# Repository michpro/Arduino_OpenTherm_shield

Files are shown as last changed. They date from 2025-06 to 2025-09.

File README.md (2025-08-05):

# **Arduino UNO OpenTherm Shield**

- [**Arduino UNO OpenTherm Shield**](#arduino-uno-opentherm-shield)
  - [**Overview**](#overview)
    - [**Features**](#features)
  - [**Schematic diagram**](#schematic-diagram)
  - [**Module visualisation**](#module-visualisation)
  - [**Assembly**](#assembly)
  - [**Production files**](#production-files)
  - [**Testing out the hardware**](#testing-out-the-hardware)
    - [Prerequisites](#prerequisites)
    - [Instructions](#instructions)
    - [Notes](#notes)
  - [**Software**](#software)
  - [**Reporting bugs**](#reporting-bugs)
  - [**License**](#license)
    - [**Hardware**](#hardware)
    - [**Software**](#software-1)
  - [**Support**](#support)

---

## **Overview**
The Arduino OpenTherm Shield is an open-source hardware interface designed to enable an Arduino microcontroller to communicate with heating systems using the OpenTherm protocol.
OpenTherm is a point-to-point communication protocol commonly used in modern heating systems for efficient control and monitoring.
This shield provides the necessary voltage conversion, electrical isolation, and signal conditioning to interface the Arduinos 5V or 3.3V logic
with the OpenTherm bus, which typically operates at higher voltages (24V).

  ### **Features**
  * OpenTherm slave interface to communicate with a boiler
  * OpenTherm master interface to communicate with a thermostat
  * can implement master, slave and gateway modes
  * built-in (3.3-5V) to 24V DC-DC step up converter
  * Arduino UNO compatible shield

This work is based on [otgw.tclcode.com](https://otgw.tclcode.com) project.

---

## **Schematic diagram**
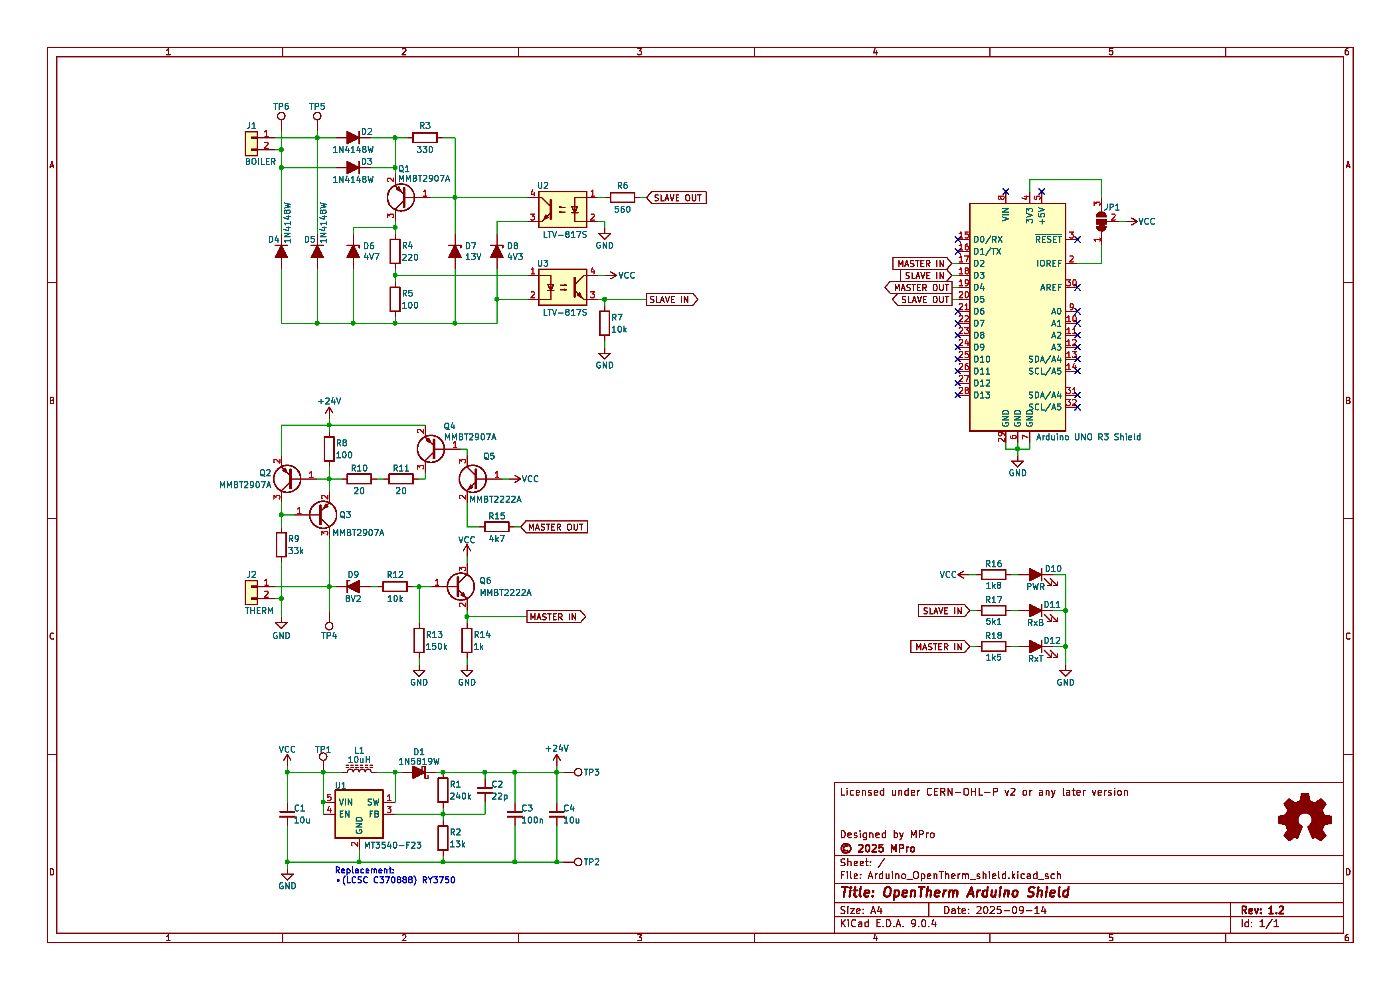
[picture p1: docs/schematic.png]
wiring diagram


## **Module visualisation**
(click on the image to see the 3D model)
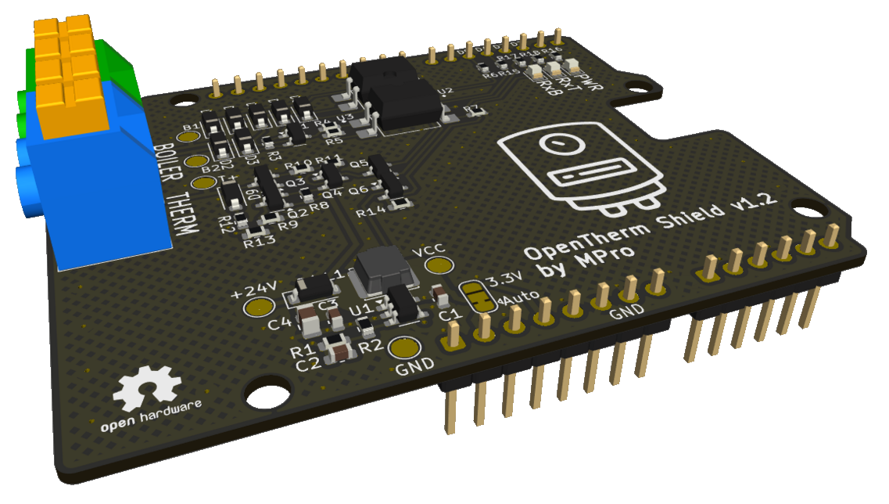
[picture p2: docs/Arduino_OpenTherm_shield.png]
Arduino UNO OpenTherm Shield
<p align="center"></p>

## **Assembly**
[Interactive BOM and placement](https://michpro.github.io/Arduino_OpenTherm_shield/ibom.html)

For Arduino UNO:
* JP1 jumper – leave in the Auto position (V<sub>cc</sub> from IOREF).

For WeMos D1 UNO:
* JP1 jumper - this board is not fully compatible with Arduino specifications - the IOREF pin on this board should have a voltage of 3.3V, but it has 5V. Therefore, cut the default jumper between the Auto and V<sub>cc</sub> pads and use a drop of tin to connect the V<sub>cc</sub> pad to 3.3V.<br>*You can also modify the WeMos D1 UNO so that the IOREF pin has the correct voltage of 3.3V*.

Other boards:
* This shield should also be compatible with other boards. You only need to check the correct voltage on the IOREF pin (and possibly make a change as for WeMos D1 UNO) and, if necessary, adjust the software to the board definition.

## **Production files**
Production files can be found [**here**](./production/).

---

## **Testing out the hardware**
Below are the start-up instructions for the ["shield_test.ino"](./software/shield_test/shield_test.ino) Arduino program, a diagnostic tool designed to test and validate the electrical and communication integrity between a boiler and thermostat circuits on the OpenTherm shield. These instructions guide you through the process step-by-step, ensuring you can verify your hardware setup correctly.

### Prerequisites
- **Arduino Board**: Use an AVR family board (e.g., Arduino UNO).
- **OpenTherm Shield**: Ensure it is properly connected to the Arduino.
- **Computer**: Equipped with Arduino IDE or a serial monitor software.
- **Multimeter**: Required for measuring voltages and currents.
- **Two Wires**: Needed to connect the BOILER and THERM terminals during testing.

### Instructions

1. **Upload the Program**
   - Load the ["shield_test.ino"](./software/shield_test/shield_test.ino) program onto your Arduino board (Arduino UNO preffered) using the Arduino IDE.<br>
    *If necessary, adjust the pins used in the programme.*

2. **Open Serial Monitor**
   - Launch the serial monitor in the Arduino IDE or your preferred serial terminal software.
   - Set the baud rate to **115200**.

3. **Initial Setup**
   - Disconnect the 'THERM' and 'BOILER' terminals from each other if they are connected.
   - Check the LEDs on the shield:
     - **'PWR'** and **'RxT'** LEDs should be lit.
     - **'RxB'** LED should be off.
   - The serial monitor will display a prompt. If the LED statuses match, type **`y`** and press Enter to proceed.

4. **Voltage Measurement 1**
   - Use a multimeter to measure the voltage between the **+24V test point** and **GND**.
   - Expected range: **23.5V to 24.5V**.
   - If within range, type **`y`** in the serial monitor to proceed.

5. **Voltage Measurement 2**
   - Measure the voltage between the **T+ test point** and **GND**.
   - Expected value: Approximately **24V**.
   - If correct, type **`y`** to proceed.

6. **Current Measurement 1**
   - Measure the current flowing between **T+** and **GND**.
   - Expected range: **5mA to 9mA**.
   - Verify that the **RxT LED** is **not lit** during this measurement.
   - If correct, type **`y`** to proceed.

7. **Activate MASTER-OUT and Current Measurement 2**
   - The program will activate the 'MASTER-OUT' line (you’ll see a message in the serial monitor).
   - Measure the current between **T+** and **GND** again.
   - Expected range: **17mA to 23mA**.
   - Ensure the **RxT LED** remains **not lit**.
   - If correct, type **`y`** to proceed.

8. **Connect Terminals and Voltage Measurement 3**
   - Connect the **BOILER** and **THERM** terminals using two wires (polarity does not matter).
   - Measure the voltage between test points **B1** and **B2**.
   - Expected range: **15V to 18V**.
   - If within range, type **`y`** to proceed.

9. **Check RxB LED**
   - The program will activate 'MASTER-OUT' again.
   - Observe the **'RxB' LED**; it should **light up**.
   - If it does, type **`y`** to proceed.

10. **Activate SLAVE-OUT and Voltage Measurement 4**
    - The program will activate the 'SLAVE-OUT' line.
    - Check that the **RxT LED** **stops lighting up**.
    - Measure the voltage between **B1** and **B2** again.
    - Expected range: **5V to 7V**.
    - If correct, type **`y`** to proceed.

11. **Test Result**
    - If all steps are completed successfully, the serial monitor will display:
      ```
      *****************
      *  TEST PASSED  *
      *****************
      ```
    - If any step fails, it will show:
      ```
      *****************
      * TEST FAIL !!! *
      *****************
      ```

12. **Continuous Testing (if passed)**
    - If the test passes, the program will enter a continuous testing mode.
    - It will repeatedly check communication between the boiler and thermostat, printing:
      - **"Boiler inbound, thermostat outbound ... OK"** or **"Failed"** with a reason.
      - **"Boiler outbound, thermostat inbound ... OK"** or **"Failed"** with a reason.

### Notes
- **Test Points and LEDs**: Ensure you correctly identify the test points (+24V, T+, GND, B1, B2) and LEDs (PWR, RxT, RxB) on the OpenTherm shield.
- **Safety**: Exercise caution when measuring voltages and currents to avoid short circuits.
- **Troubleshooting**: If a measurement falls outside the expected range:
  - Double-check your connections and multimeter settings.
  - Retry the step. Persistent issues may indicate a problem with the shield or setup.

<br>

***Follow these instructions carefully to test and validate your OpenTherm shield setup. Each step requires confirmation via the serial monitor, so keep it open and active throughout the process. Successful completion ensures your boiler and thermostat circuits are functioning correctly.***

---

## **Software**
- Recommended library for use in your OpenTherm projects: 
  [https://github.com/ihormelnyk/opentherm_library](https://github.com/ihormelnyk/opentherm_library)

---

## **Reporting bugs**

[Create an issue on GitHub](https://github.com/michpro/Arduino_OpenTherm_shield/issues)

---

## **License**
Copyright © 2025 Michal Protasowicki

### **Hardware**
  * Hardware part of this project is released under CERN Open Hardware Licence Version 2 - Permissive.

    

### **Software**
  * Software part of this project is released under MIT Licence.

    

---

## **Support**
If You find my projects interesting and You wanted to support my work, You can give me a cup of coffee or a keg of beer :)

&nbsp;&nbsp;&nbsp;&nbsp;&nbsp;&nbsp;&nbsp;&nbsp;&nbsp;&nbsp;

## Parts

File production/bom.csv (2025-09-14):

Designator | Footprint | Quantity | Value | LCSC Part #
C1 | 0603 | 1 | 10u | C19702
C2 | 0603 | 1 | 22p | C1653
C3 | 0603 | 1 | 100n | C14663
C4 | 0805 | 1 | 10u | C440198
D1 | D_SOD-123 | 1 | 1N5819W | C8598
D10 | 0805 | 1 | PWR | C84256
D11 | 0805 | 1 | RxB | C2297
D12 | 0805 | 1 | RxT | C2296
D2, D3, D4, D5 | D_SOD-123 | 4 | 1N4148W | C7420318
D6 | D_SOD-123 | 1 | 4V7 | C19077400
D7 | D_SOD-123 | 1 | 13V | C22399883
D8 | D_SOD-123 | 1 | 4V3 | C19077399
D9 | D_SOD-123 | 1 | 8V2 | C22399882
L1 | Inductor_4.2x4.4mm | 1 | 10uH | C177242
Q1, Q2, Q3, Q4 | SOT-23 | 4 | MMBT2907A | C7420352
Q5, Q6 | SOT-23 | 2 | MMBT2222A | C8512
R1 | 0603 | 1 | 240k | C4197
R10, R11 | 0603 | 2 | 20 | C22950
R12, R7 | 0603 | 2 | 10k | C25804
R13 | 0603 | 1 | 150k | C22807
R14 | 0603 | 1 | 1k | C21190
R15 | 0603 | 1 | 4k7 | C23162
R16 | 0603 | 1 | 1k8 | C4177
R17 | 0603 | 1 | 5k1 | C23186
R18 | 0603 | 1 | 1k5 | C22843
R2 | 0603 | 1 | 13k | C22797
R3 | 0603 | 1 | 330 | C23138
R4 | 0603 | 1 | 220 | C22962
R5, R8 | 0603 | 2 | 100 | C22775
R6 | 0603 | 1 | 560 | C23204
R9 | 0603 | 1 | 33k | C4216
U1 | SOT-23-5 | 1 | MT3540-F23 | C181783
U2, U3 | SMDIP-4_W9.53mm | 2 | LTV-817S | C109227

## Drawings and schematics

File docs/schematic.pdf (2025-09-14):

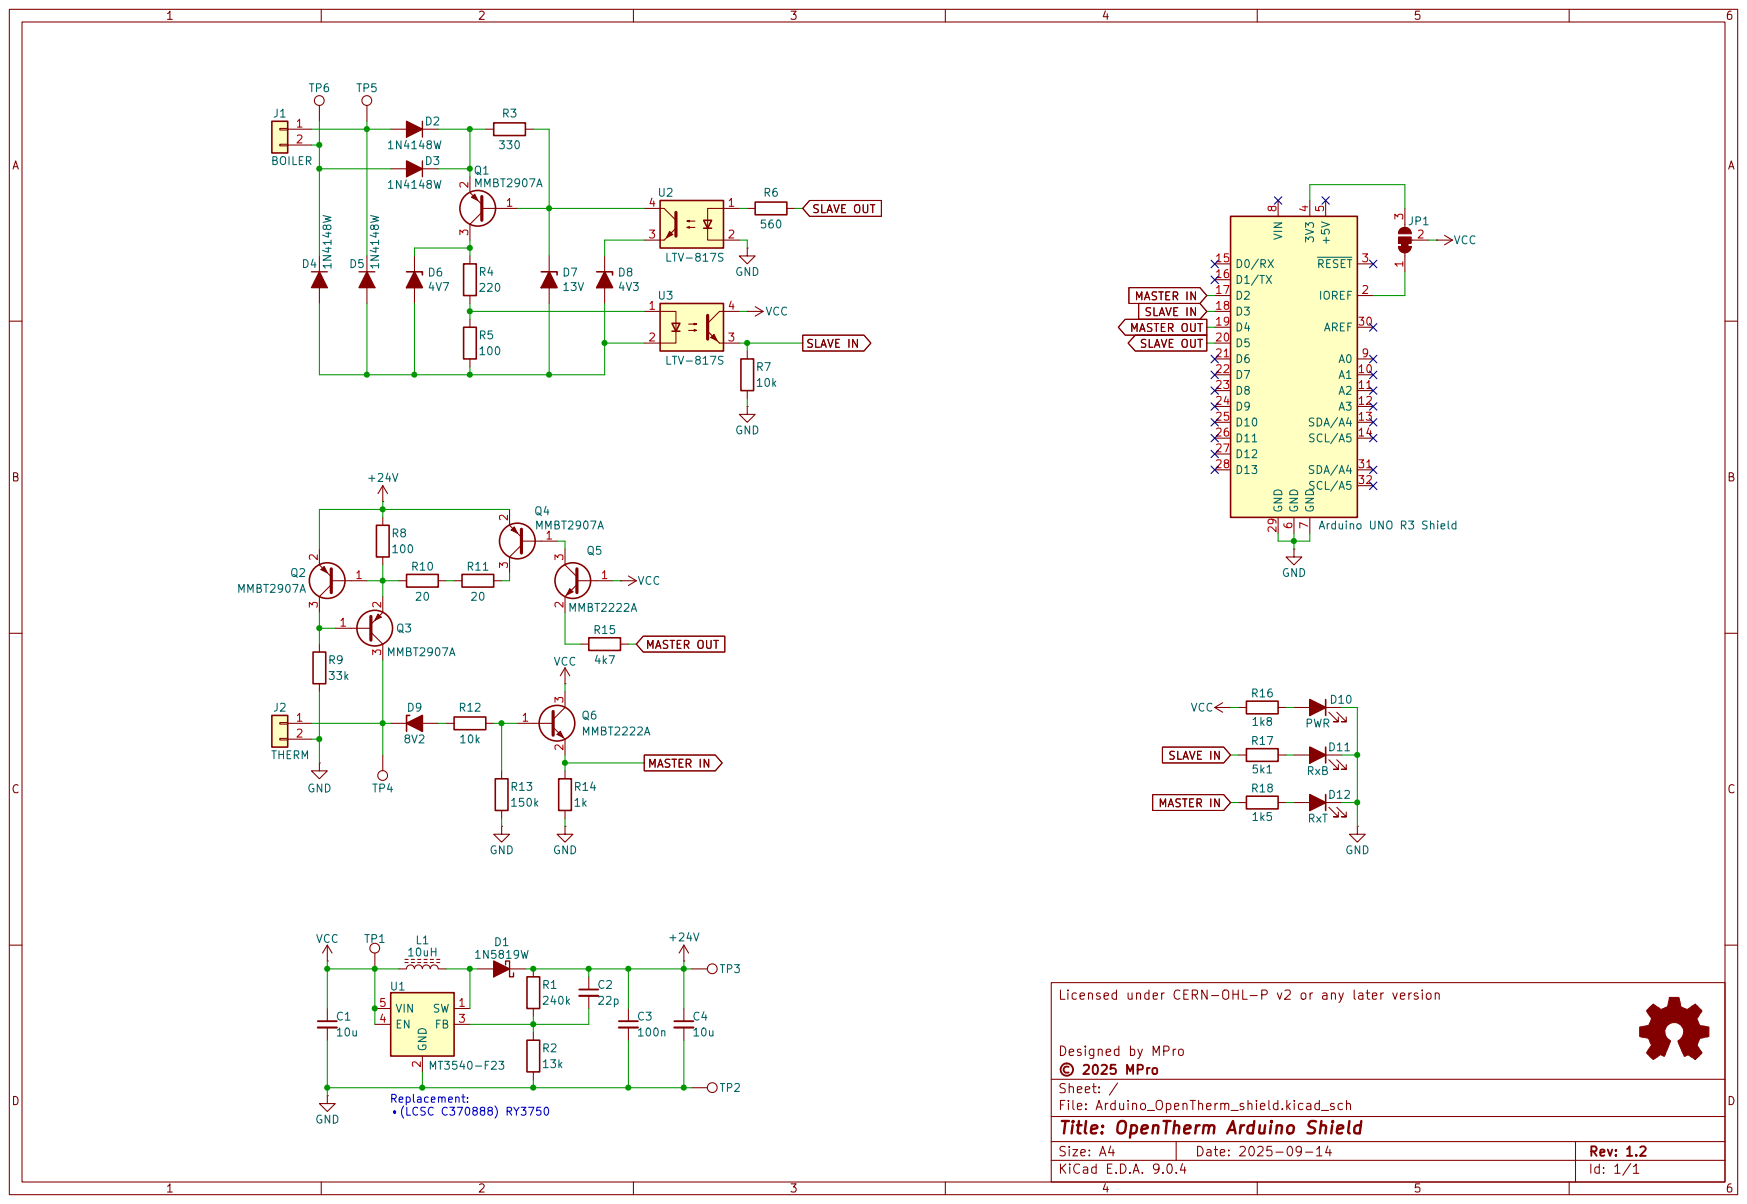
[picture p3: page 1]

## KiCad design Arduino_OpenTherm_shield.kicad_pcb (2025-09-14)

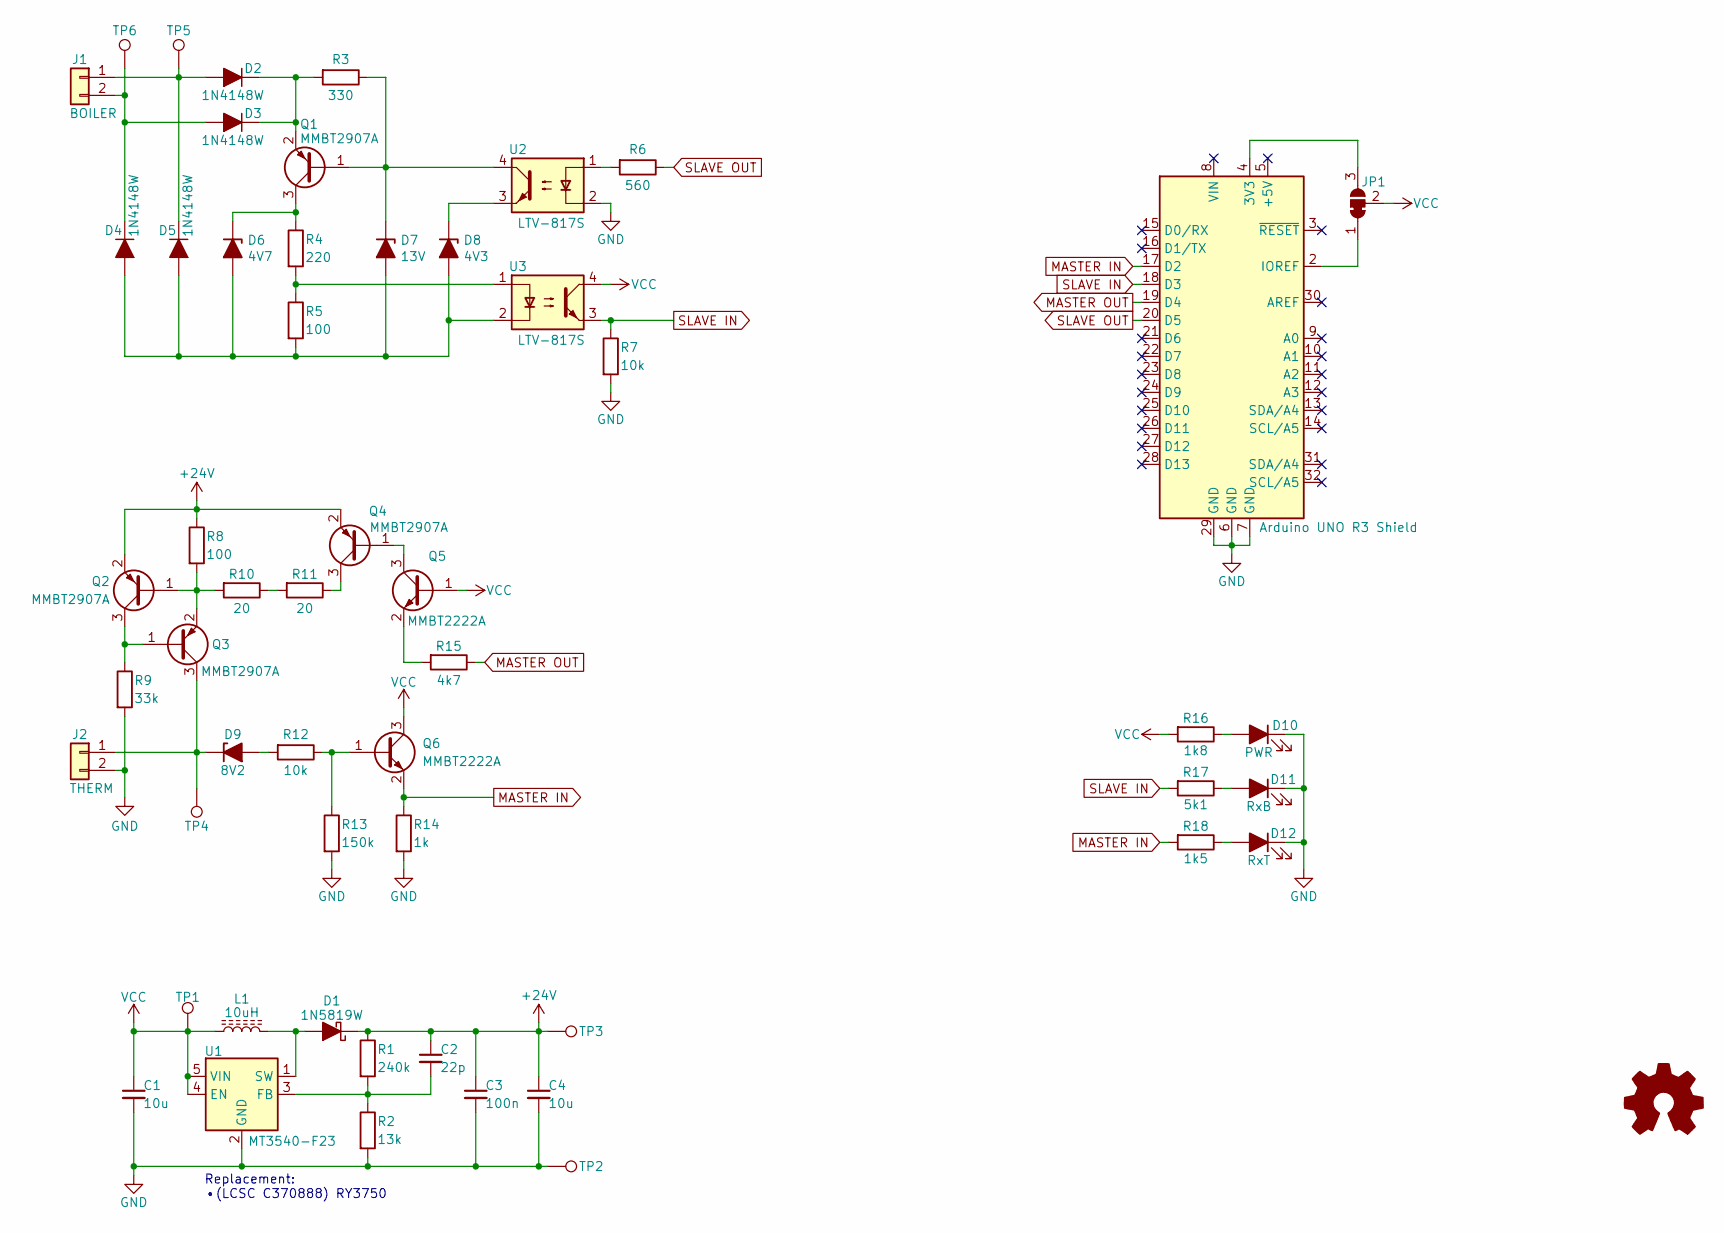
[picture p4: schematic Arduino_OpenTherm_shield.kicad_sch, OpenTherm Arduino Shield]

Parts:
A1: Arduino UNO R3 Shield; Arduino_UNO_R3_WithMountingHoles_Profiled; LCSC ------
C1: 10u; C_0603_1608Metric; LCSC C19702
C2: 22p; C_0603_1608Metric; LCSC C1653
C3: 100n; C_0603_1608Metric; LCSC C14663
C4: 10u; C_0805_2012Metric; LCSC C440198
D1: 1N5819W; D_SOD-123; LCSC C8598
D2, D3, D4, D5: 1N4148W; D_SOD-123; LCSC C7420318
D6: 4V7; D_SOD-123; LCSC C19077400
D7: 13V; D_SOD-123; LCSC C22399883
D8: 4V3; D_SOD-123; LCSC C19077399
D9: 8V2; D_SOD-123; LCSC C22399882
D10: PWR; LED_0805_2012Metric; LCSC C84256
D11: RxB; LED_0805_2012Metric; LCSC C2297
D12: RxT; LED_0805_2012Metric; LCSC C2296
J1: BOILER; Altech_AK100_1x02_P5.00mm; LCSC ------
J2: THERM; Altech_AK100_1x02_P5.00mm; LCSC ------
JP1: VCC; SolderJumper-3_P1.3mm_Bridged12_RoundedPad1.0x1.5mm; LCSC ------
L1: 10uH; Inductor_4.2x4.4mm; LCSC C177242
LOGO3: Logo_Open_Hardware_Small; OSHW-Logo2_7.3x6mm_SilkScreen
Q1, Q2, Q3, Q4: MMBT2907A; SOT-23; LCSC C7420352
Q5, Q6: MMBT2222A; SOT-23; LCSC C8512
R1: 240k; R_0603_1608Metric; LCSC C4197
R2: 13k; R_0603_1608Metric; LCSC C22797
R3: 330; R_0603_1608Metric; LCSC C23138
R4: 220; R_0603_1608Metric; LCSC C22962
R5, R8: 100; R_0603_1608Metric; LCSC C22775
R6: 560; R_0603_1608Metric; LCSC C23204
R7, R12: 10k; R_0603_1608Metric; LCSC C25804
R9: 33k; R_0603_1608Metric; LCSC C4216
R10, R11: 20; R_0603_1608Metric; LCSC C22950
R13: 150k; R_0603_1608Metric; LCSC C22807
R14: 1k; R_0603_1608Metric; LCSC C21190
R15: 4k7; R_0603_1608Metric; LCSC C23162
R16: 1k8; R_0603_1608Metric; LCSC C4177
R17: 5k1; R_0603_1608Metric; LCSC C23186
R18: 1k5; R_0603_1608Metric; LCSC C22843
TP1: VCC; TestPoint_Pad_D2.0mm; LCSC ------
TP2: GND; TestPoint_Pad_D2.0mm; LCSC ------
TP3: +24V; TestPoint_Pad_D2.0mm; LCSC ------
TP4: T+; TestPoint_Pad_D2.0mm; LCSC ------
TP5: B1; TestPoint_Pad_D2.0mm; LCSC ------
TP6: B2; TestPoint_Pad_D2.0mm; LCSC ------
U1: MT3540-F23; SOT-23-5; LCSC C181783
U2, U3: LTV-817S; SMDIP-4_W9.53mm; LCSC C109227

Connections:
+24V: C2.1, C3.1, C4.1, D1.1 (K), Q2.2 (E), Q4.2 (E), R1.1, R8.1, TP3.1
GND: A1.6 (GND), A1.7 (GND), A1.29 (GND), C1.2, C3.2, C4.2, D10.1 (K), D11.1 (K), D12.1 (K), J2.2, R2.2, R7.2, R9.2, R13.2, R14.2, TP2.1, U1.2 (GND), U2.2
MASTER IN: A1.17 (D2), Q6.2 (E), R14.1, R18.2
MASTER OUT: A1.19 (D4), R15.1
unnamed: A1.4 (3V3), JP1.3 (B)
unnamed: A1.2 (IOREF), JP1.1 (A)
unnamed: D1.2 (A), L1.2, U1.1 (SW)
unnamed: D2.2 (A), D5.1 (K), J1.1, TP5.1
unnamed: D2.1 (K), D3.1 (K), Q1.2 (E), R3.2
unnamed: D3.2 (A), D4.1 (K), J1.2, TP6.1
unnamed: D4.2 (A), D5.2 (A), D6.2 (A), D7.2 (A), D8.2 (A), R5.2, U3.2
unnamed: D6.1 (K), Q1.3 (C), R4.1
unnamed: D7.1 (K), Q1.1 (B), R3.1, U2.4
unnamed: D8.1 (K), U2.3
unnamed: D9.2 (A), R12.2
unnamed: D9.1 (K), J2.1, Q3.3 (C), TP4.1
unnamed: D10.2 (A), R16.1
unnamed: D11.2 (A), R17.1
unnamed: D12.2 (A), R18.1
unnamed: Q2.1 (B), Q3.2 (E), R8.2, R10.2
unnamed: Q2.3 (C), Q3.1 (B), R9.1
unnamed: Q4.1 (B), Q5.3 (C)
unnamed: Q4.3 (C), R11.1
unnamed: Q5.2 (E), R15.2
unnamed: Q6.1 (B), R12.1, R13.1
unnamed: R4.2, R5.1, U3.1
unnamed: R6.2, U2.1
unnamed: R10.1, R11.2
unnamed: C2.2, R1.2, R2.1, U1.3 (FB)
SLAVE IN: A1.18 (D3), R7.1, R17.2, U3.3
SLAVE OUT: A1.20 (D5), R6.1
VCC: C1.1, JP1.2 (C), L1.1, Q5.1 (B), Q6.3 (C), R16.2, TP1.1, U1.4 (EN), U1.5 (VIN), U3.4

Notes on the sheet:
Replacement: •(LCSC C370888) RY3750

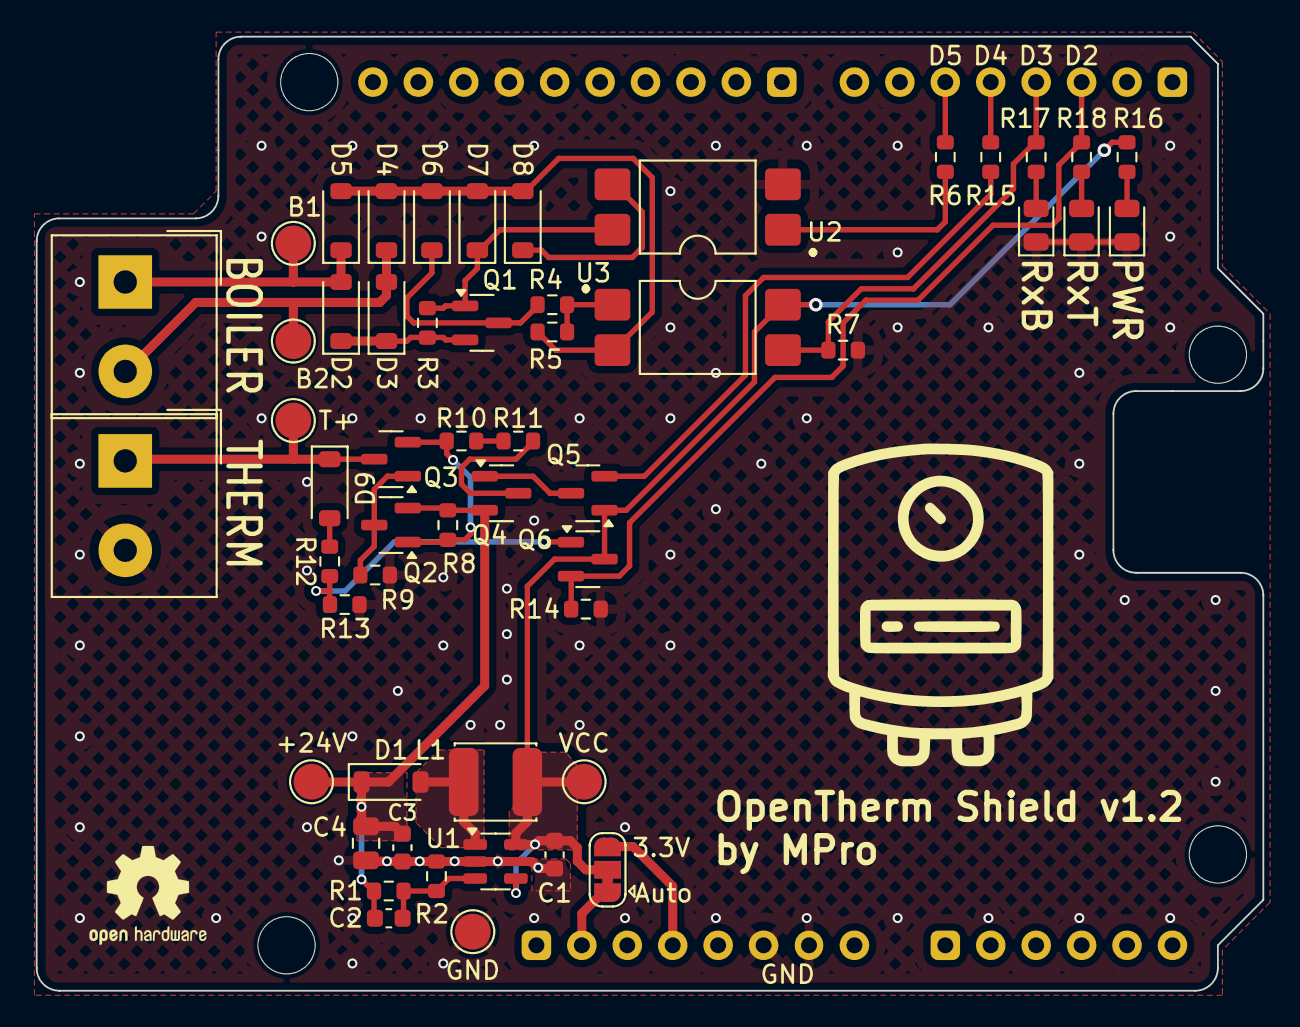
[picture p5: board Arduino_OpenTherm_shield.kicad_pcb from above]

Board: 2 copper layers, 68.6 x 53.3 mm, 55 parts (0 on the bottom side), 32 nets.

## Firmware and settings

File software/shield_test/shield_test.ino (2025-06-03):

/**
 * \file    shield_test.ino
 * \brief   This Arduino program is a diagnostic tool designed to test and validate the electrical and communication integrity
 *          between a boiler and thermostat circuits on the OpenTherm shield.
 *          It guides the user through a step-by-step verification process via serial prompts, checking voltages, currents, and LED statuses.
 *          The setup() function initializes hardware pins and performs sequential tests with user measurements and confirmation,
 *          while the loop() continuously validates bidirectional signal communication between boiler and thermostat if all initial tests pass.
 *          The program provides real-time feedback via serial output, indicating "TEST PASSED" or "TEST FAIL" based on user input and hardware responses.
*
 * \copyright SPDX-FileCopyrightText: Copyright 2025 Michal Protasowicki
 *
 * \license SPDX-License-Identifier: MIT
 *
 */

#if !defined(ARDUINO_ARCH_AVR)
    #error "Use only with Arduino AVR family!!!"
#endif

#include <Arduino.h>

// Arduino UNO
const int   MASTER_IN                   {2};
const int   SLAVE_IN                    {3};
const int   MASTER_OUT                  {4};
const int   SLAVE_OUT                   {5};

const int   DELAY_DEV_MS                {40};
const int   DELAY_LOOP_MS               {2000};

const char  CONFIRM_M_STR[]     PROGMEM {"If the measurement is correct, send 'y' to proceed to the next step."};
const char  CONFIRM_P_STR[]     PROGMEM {"If so, press 'y' to proceed to the next step."};
const char  MASTER_ACT_STR[]    PROGMEM {"The 'MASTER-OUT' line has been activated."};
const char  RXT_NLIT_STR[]      PROGMEM {"The RxT LED should not be lit during the measurement."};
const char  MEAS_B1_B2_STR[]    PROGMEM {"Measure the voltage between test points B1 and B2."};
const char  FAILED_STR[]        PROGMEM {"Failed"};
const char  OK_STR[]            PROGMEM {"OK"};
const char  LINE_STR[]          PROGMEM {"----------------------------------------------------------------------------------"};
const char  STARS_STR[]         PROGMEM {"*****************"};

bool        next                        {false};

bool waitForYes(void)
{
    bool    result  {true};
    bool    exit    {false};
    char    chr     {0};

    while (!exit)
    {
        while (!SERIAL_PORT_MONITOR.available()) {};
        while (SERIAL_PORT_MONITOR.available() > 0)
        {
            chr = SERIAL_PORT_MONITOR.read();

            switch (chr)
            {
                case 'n':
                case 'N':
                    exit = true;
                    result = false;
                    break;
                case 'y':
                case 'Y':
                    exit = true;
                    break;
                default:
                    break;
            }
        }
    }

    return result;
}

void setup()
{
    SERIAL_PORT_MONITOR.begin(115200);
    while (!SERIAL_PORT_MONITOR) {}

    pinMode(MASTER_IN, INPUT);
    pinMode(SLAVE_IN, INPUT);
    pinMode(MASTER_OUT, OUTPUT);                                    // low output = high current, high output = low current
    pinMode(SLAVE_OUT, OUTPUT);                                     // low output = high voltage, high output = low voltage
    digitalWrite(MASTER_IN, HIGH);
    digitalWrite(MASTER_OUT, HIGH);
    digitalWrite(SLAVE_IN, HIGH);
    digitalWrite(SLAVE_OUT, LOW);

    SERIAL_PORT_MONITOR.println(F("Disconnect the 'THERM' and 'BOILER' terminals if they are connected to each other."));
    SERIAL_PORT_MONITOR.println(F("The 'PWR' and 'RxT' LEDs should light up, and the 'RxB' LED should be off."));
    SERIAL_PORT_MONITOR.println((const __FlashStringHelper *)CONFIRM_P_STR);
    next = waitForYes();
    SERIAL_PORT_MONITOR.println((const __FlashStringHelper *)LINE_STR);

    if (next)
    {
        SERIAL_PORT_MONITOR.println(F("Measure the voltage between the +24V test point and GND."));
        SERIAL_PORT_MONITOR.println(F("It should be between 23.5V and 24.5V."));
        SERIAL_PORT_MONITOR.println((const __FlashStringHelper *)CONFIRM_M_STR);
        next = waitForYes();
        SERIAL_PORT_MONITOR.println((const __FlashStringHelper *)LINE_STR);
    }

    if (next)
    {
        SERIAL_PORT_MONITOR.println(F("Measure the voltage between the T+ test point and GND."));
        SERIAL_PORT_MONITOR.println(F("It should be approximately 24V."));
        SERIAL_PORT_MONITOR.println((const __FlashStringHelper *)CONFIRM_M_STR);
        next = waitForYes();
        SERIAL_PORT_MONITOR.println((const __FlashStringHelper *)LINE_STR);
    }

    if (next)
    {
        SERIAL_PORT_MONITOR.println(F("Measure the current flowing between the T+ test point and GND."));
        SERIAL_PORT_MONITOR.println(F("It should be between 5mA and 9mA."));
        SERIAL_PORT_MONITOR.println((const __FlashStringHelper *)RXT_NLIT_STR);
        SERIAL_PORT_MONITOR.println((const __FlashStringHelper *)CONFIRM_M_STR);
        next = waitForYes();
        SERIAL_PORT_MONITOR.println((const __FlashStringHelper *)LINE_STR);
    }

    if (next)
    {
        digitalWrite(MASTER_OUT, LOW);
        SERIAL_PORT_MONITOR.println((const __FlashStringHelper *)MASTER_ACT_STR);
        SERIAL_PORT_MONITOR.println(F("Measure the current flowing between the T+ test point and GND again."));
        SERIAL_PORT_MONITOR.println(F("It should be between 17mA and 23mA."));
        SERIAL_PORT_MONITOR.println((const __FlashStringHelper *)RXT_NLIT_STR);
        SERIAL_PORT_MONITOR.println((const __FlashStringHelper *)CONFIRM_M_STR);
        next = waitForYes();
        SERIAL_PORT_MONITOR.println((const __FlashStringHelper *)LINE_STR);
        digitalWrite(MASTER_OUT, HIGH);
    }

    if (next)
    {
        SERIAL_PORT_MONITOR.println(F("Connect the BOILER and THERM terminals with two wires [polarity is irrelevant]."));
        SERIAL_PORT_MONITOR.println((const __FlashStringHelper *)MEAS_B1_B2_STR);
        SERIAL_PORT_MONITOR.println(F("It should be between 15V and 18V."));
        SERIAL_PORT_MONITOR.println((const __FlashStringHelper *)CONFIRM_M_STR);
        next = waitForYes();
        SERIAL_PORT_MONITOR.println((const __FlashStringHelper *)LINE_STR);
    }

    if (next)
    {
        digitalWrite(MASTER_OUT, LOW);
        SERIAL_PORT_MONITOR.println((const __FlashStringHelper *)MASTER_ACT_STR);
        SERIAL_PORT_MONITOR.println(F("The 'RxB' LED should light up."));
        SERIAL_PORT_MONITOR.println((const __FlashStringHelper *)CONFIRM_P_STR);
        next = waitForYes();
        SERIAL_PORT_MONITOR.println((const __FlashStringHelper *)LINE_STR);
        digitalWrite(MASTER_OUT, HIGH);
    }

    if (next)
    {
        digitalWrite(SLAVE_OUT, HIGH);
        SERIAL_PORT_MONITOR.println(F("The 'SLAVE-OUT' line has been activated."));
        SERIAL_PORT_MONITOR.println(F("The RxT LED should stop lighting up."));
        SERIAL_PORT_MONITOR.println((const __FlashStringHelper *)MEAS_B1_B2_STR);
        SERIAL_PORT_MONITOR.println(F("It should be between 5V and 7V."));
        SERIAL_PORT_MONITOR.println((const __FlashStringHelper *)CONFIRM_M_STR);
        next = waitForYes();
        SERIAL_PORT_MONITOR.println((const __FlashStringHelper *)LINE_STR);
        digitalWrite(SLAVE_OUT, LOW);
    }

    
    SERIAL_PORT_MONITOR.println((const __FlashStringHelper *)STARS_STR);
    if (next)
    {
        SERIAL_PORT_MONITOR.println(F("*  TEST PASSED  *"));
    } else
    {
        SERIAL_PORT_MONITOR.println(F("* TEST FAIL !!! *"));
    }
    SERIAL_PORT_MONITOR.println((const __FlashStringHelper *)STARS_STR);
}

void loop()
{
    if (next)
    {
        Serial.print(F("Boiler inbound, thermostat outbound ... "));
        digitalWrite(MASTER_OUT, HIGH);
        digitalWrite(SLAVE_OUT, HIGH);
        delay(DELAY_DEV_MS);

        if ((LOW == digitalRead(MASTER_IN)) && (LOW == digitalRead(SLAVE_IN)))
        {
            digitalWrite(MASTER_OUT, LOW);                          // thermostat out low -> boiler in high
            delay(DELAY_DEV_MS);

            if ((LOW == digitalRead(MASTER_IN)) && (HIGH == digitalRead(SLAVE_IN)))
            {
                Serial.println((const __FlashStringHelper *)OK_STR);
            } else
            {
                Serial.println((const __FlashStringHelper *)FAILED_STR);
                Serial.println(F("Boiler is not registering signal or thermostat is not sending properly"));
            }
        } else
        {
            Serial.println((const __FlashStringHelper *)FAILED_STR);
            Serial.println(F("Boiler is high even if no signal is being sent"));
        }
        
        Serial.print(F("Boiler outbound, thermostat inbound ... "));
        digitalWrite(MASTER_OUT, HIGH);
        digitalWrite(SLAVE_OUT, HIGH);
        delay(DELAY_DEV_MS);

        if ((LOW == digitalRead(MASTER_IN)) && (LOW == digitalRead(SLAVE_IN)))
        {
            digitalWrite(SLAVE_OUT, LOW);                           // boiler out low -> thermostat in high
            delay(DELAY_DEV_MS);

            if ((HIGH == digitalRead(MASTER_IN)) && (LOW == digitalRead(SLAVE_IN)))
            {
                Serial.println((const __FlashStringHelper *)OK_STR);
            } else
            {
                Serial.println((const __FlashStringHelper *)FAILED_STR);
                Serial.println(F("Thermostat is not registering signal or boiler is not sending properly"));
            }
        } else
        {
            Serial.println((const __FlashStringHelper *)FAILED_STR);
            Serial.println(F("Thermostat is high even if no signal is being sent"));
        }

        delay(DELAY_LOOP_MS);
    }
}

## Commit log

2025-04-01 HW rev 1.1
    [Arduino_OpenTherm_shield.kicad_pcb, Arduino_OpenTherm_shield.kicad_sch, bom.csv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]
2025-04-16 Corrected value of the resistance responsible for the High state of the OT bus
    [Arduino_OpenTherm_shield.kicad_pcb, Arduino_OpenTherm_shield.kicad_sch]
2025-04-24 updated bom list
    [Arduino_OpenTherm_shield.kicad_pcb, Arduino_OpenTherm_shield.kicad_sch, bom.csv]
2025-07-11 HW rev 1.2 [fixed translation of MASTER_IN signal logic levels]
    [Arduino_OpenTherm_shield.kicad_pcb, Arduino_OpenTherm_shield.kicad_sch, bom.csv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]
2025-09-14 RxB LED brightness adjusted
    [Arduino_OpenTherm_shield.kicad_pcb, Arduino_OpenTherm_shield.kicad_sch, bom.csv]

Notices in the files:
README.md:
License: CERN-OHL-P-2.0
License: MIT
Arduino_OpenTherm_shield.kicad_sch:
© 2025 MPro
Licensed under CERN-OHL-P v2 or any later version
